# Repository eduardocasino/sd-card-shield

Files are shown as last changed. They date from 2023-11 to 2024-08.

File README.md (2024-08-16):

# SD Card Shield for 8-bit computers

## About

This is a functionally equivalent recreation of the latest version of Corsham's [SD Card Shield](https://www.corshamtech.com/new-version-of-sd-card-shield/). Sadly, Bob Applegate, the man and soul behind Corsham Technologies, passed away in 2023 and [his shop is no longer in business](https://www.corshamtech.com/bad-news-and-the-future/).

Bob put a lot of his work under open source licenses or in the public domain, and also shared the schematics of his boards in the spirit of the emerging personal computer industry of the late 1970s. However, this information was not always complete or up to date, and never published the files to physically reproduce his PCBs (logically, as this was also a business to him) and now those boards are not available anymore.

I have been able to reverse engineer the design from the schematic of previous versions, which is available, and from photos of revisions 6 and 9.

~~WARNING: This design has not been tested yet. Use at your own risk!~~

The board has been tested working with a KIM-1 and Corsham's xKIM monitor but, still, use at your own risk!

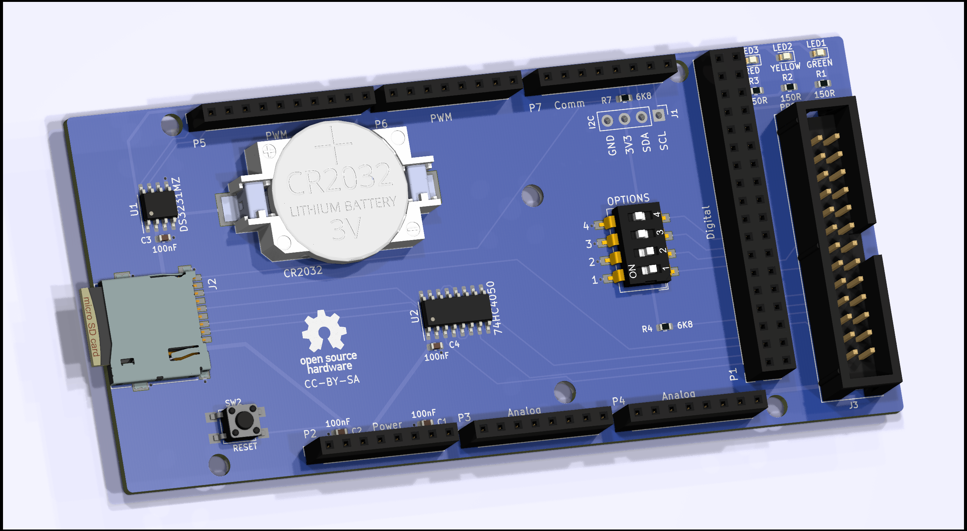
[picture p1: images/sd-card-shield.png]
components

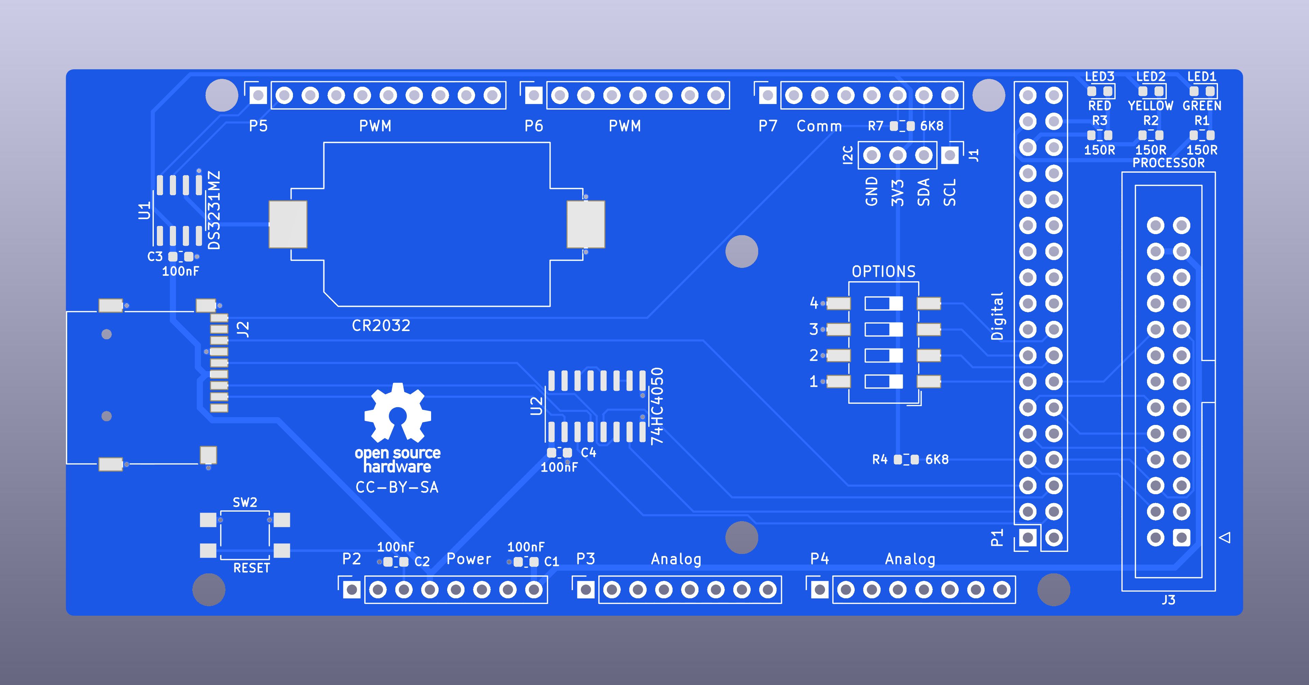
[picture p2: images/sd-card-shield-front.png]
front

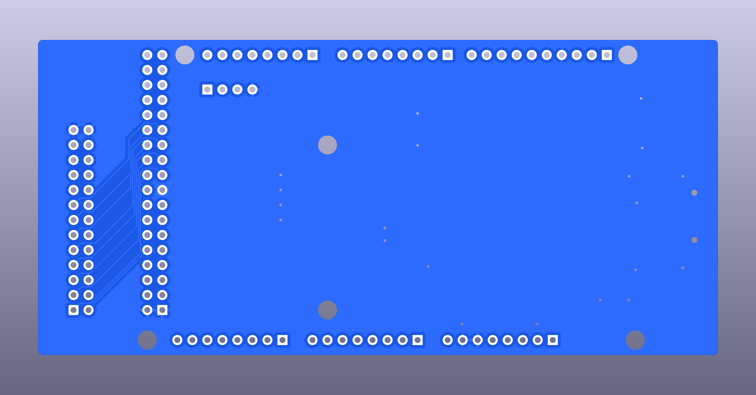
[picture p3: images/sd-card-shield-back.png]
back


## Licensing

This is a personal project that I am sharing in case it is of interest to any retrocomputing enthusiast and all the information in this repository is provided "as is", without warranty of any kind. I am not liable for any damages that may occur, whether it be to individuals, objects, KIM-1 computers, kittens or any other pets. **It should also be noted that everything in this repository is a work in progress, has not been tested and may contain errors, therefore anyone who chooses to use it does so at their own risk**.



This work is licensed under a [Creative Commons Attribution-ShareAlike 4.0 International License](http://creativecommons.org/licenses/by-sa/4.0/).

See the LICENSE.md file for details.

## Acknowledgements

* Bob Applegate, for the original design. 
* Hans Otten and his [Retro Computing blog](http://retro.hansotten.nl/). Pictures and running some checks on his rev6 board.

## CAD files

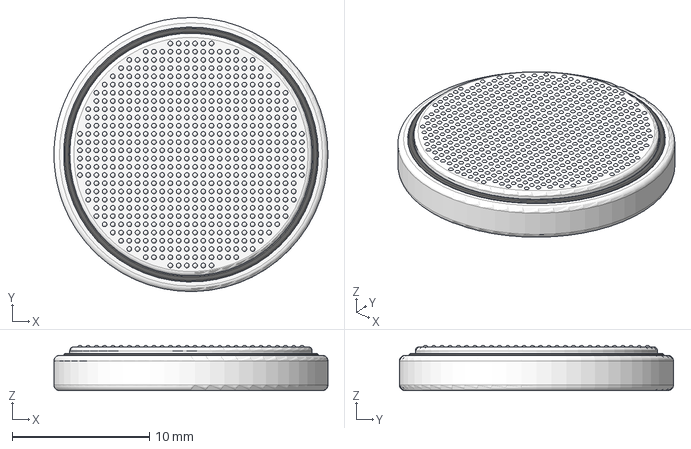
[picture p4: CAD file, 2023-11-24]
3dmodels/CR2032.stp
20.0 x 20.0 x 3.30 mm

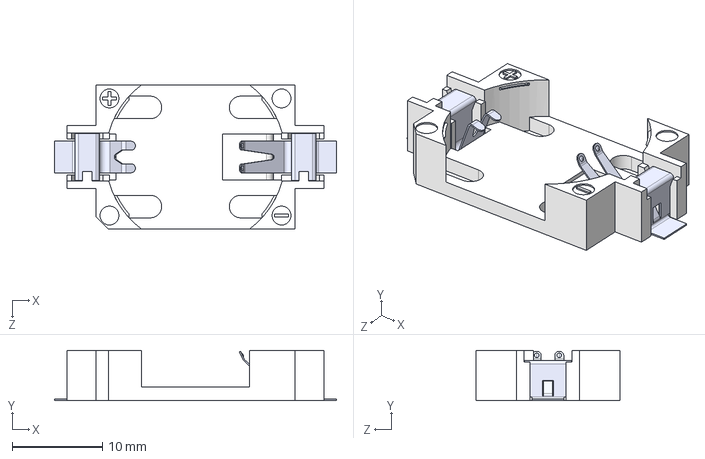
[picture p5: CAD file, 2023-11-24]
3dmodels/CR2032-BS-6-1.step
31.3 x 5.55 x 16.0 mm

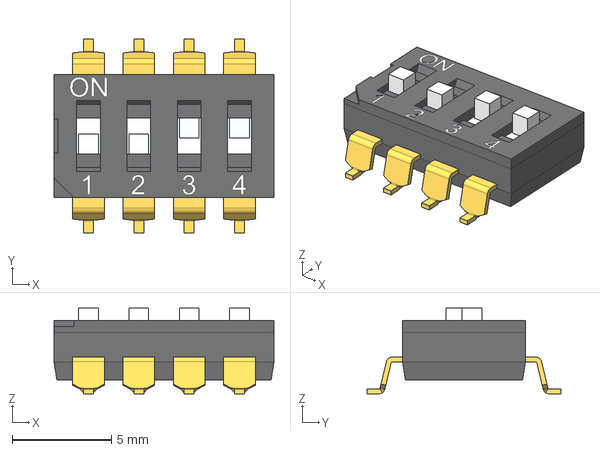
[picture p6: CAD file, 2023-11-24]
3dmodels/DIP Switch 4 positions SMD.stp
11.1 x 9.80 x 4.32 mm

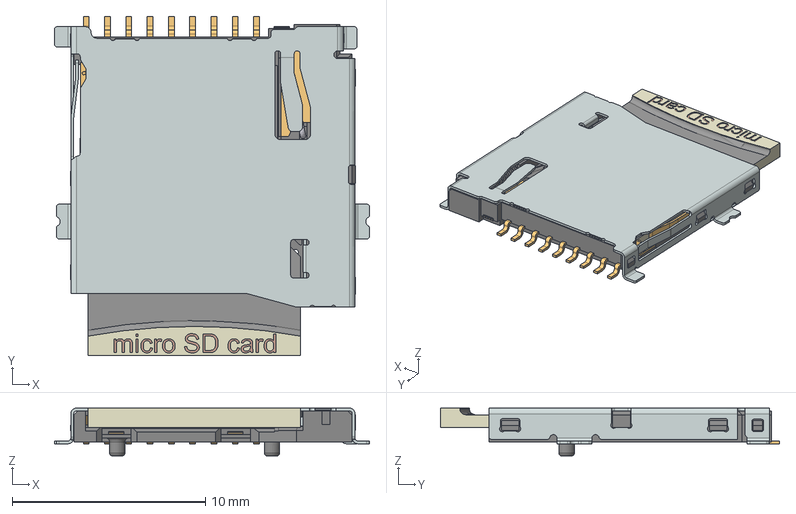
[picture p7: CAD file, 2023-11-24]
3dmodels/Micro_SD_Card_and_Holder.stp
16.3 x 17.5 x 2.48 mm
693071020811_Housing
693071020811_Guide
693071020811_Spring
693071020811_Contact
693071020811_Hook
693071020811_Agraphe
693071020811_Shielding
MicroSD

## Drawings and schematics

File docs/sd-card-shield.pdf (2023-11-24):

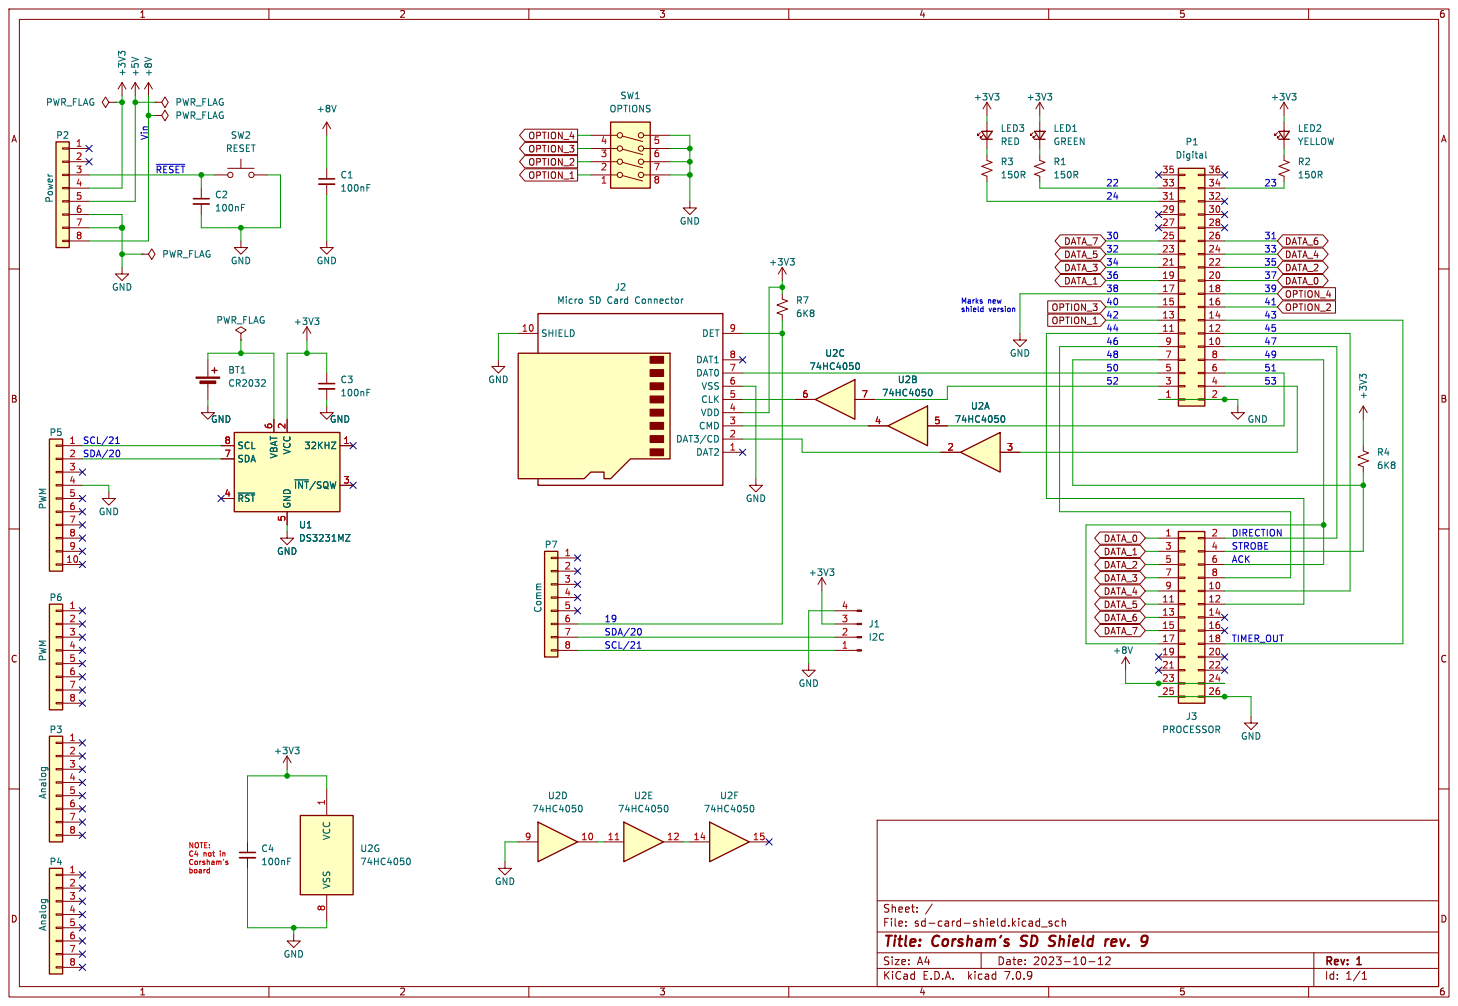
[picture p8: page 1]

6 SDA 7 SCL 8 U1 DS3231MZ GND GND +3V3 +5V

J2 Micro SD Card Connector C4

Id: 1/1 Title: Corsham's SD Shield rev. 9

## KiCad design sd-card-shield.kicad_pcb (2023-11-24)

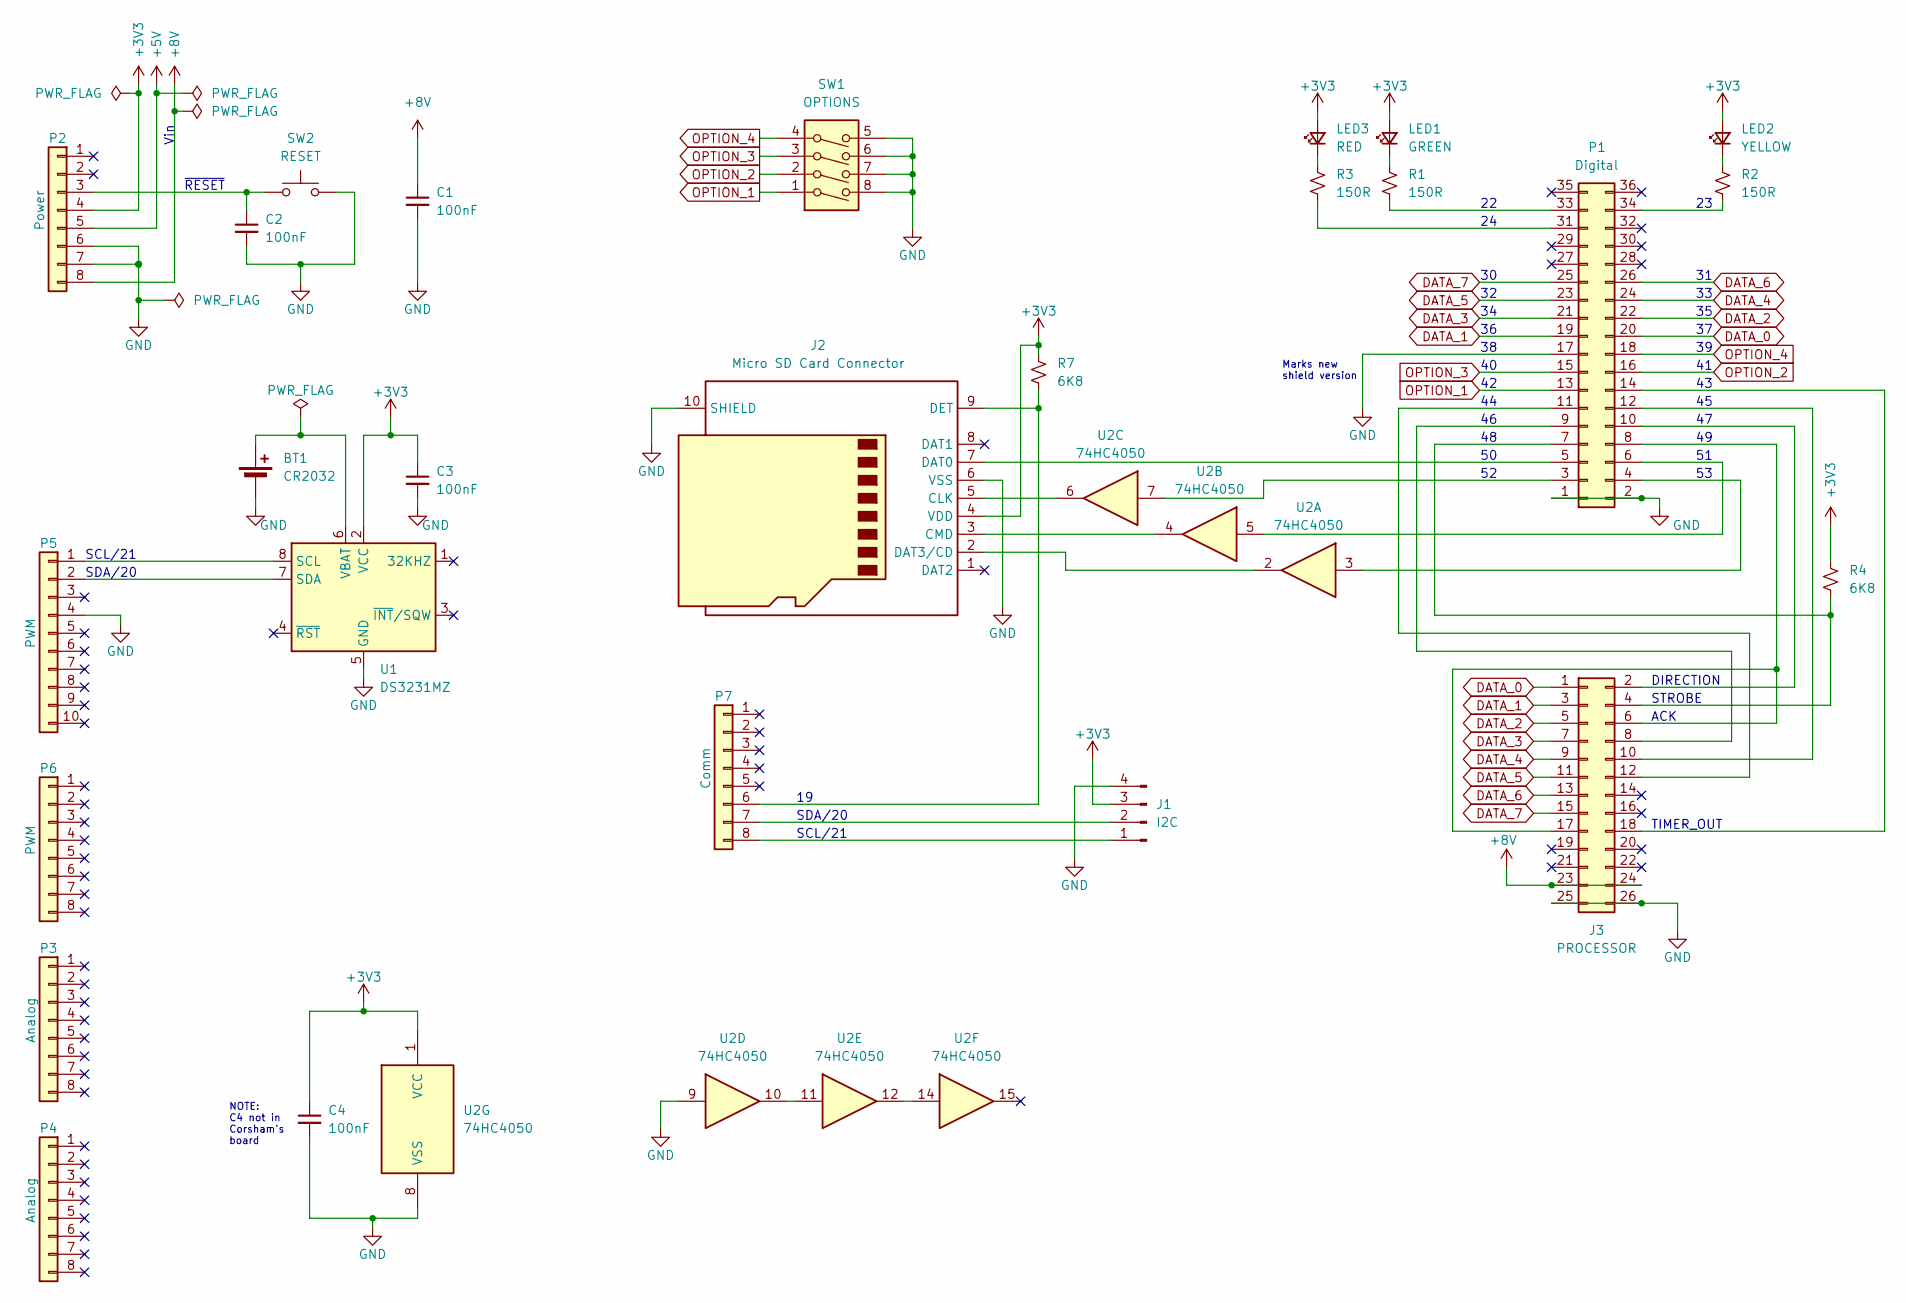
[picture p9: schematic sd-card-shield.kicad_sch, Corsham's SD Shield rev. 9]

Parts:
BT1: CR2032; BAT_CR2032-BS-06-B; LCSC C964760
C1, C2, C3, C4: 100nF; C_0603_1608Metric; LCSC C2762593
J1: I2C; PinHeader_1x04_P2.54mm_Vertical
J2: Micro SD Card Connector; SD_Card_Holder_SMD_WQ21801-B2180-7F
J3: PROCESSOR; IDC-Header_2x13_P2.54mm_Vertical; LCSC C7501247
LED1: GREEN; LED_0603_1608Metric; PART SML-D12P8WT86; LCSC C510026
LED2: YELLOW; LED_0603_1608Metric; PART SML-D12Y8WT86; LCSC C2840179
LED3: RED; LED_0603_1608Metric; PART SML-D12V8WT86; LCSC C2693607
P1: Digital; PinSocket_2x18_P2.54mm_Vertical
P2: Power; PinSocket_1x08_P2.54mm_Vertical
P3, P4: Analog; PinSocket_1x08_P2.54mm_Vertical
P5: PWM; PinSocket_1x10_P2.54mm_Vertical
P6: PWM; PinSocket_1x08_P2.54mm_Vertical
P7: Comm; PinSocket_1x08_P2.54mm_Vertical
R1, R2, R3: 150R; R_0603_1608Metric; LCSC C270843
R4, R7: 6K8; R_0603_1608Metric; LCSC C2074375
SW1: OPTIONS; SW_DIP_SPSTx04_Slide_6x10.22_P2.54mm_DSIC04LSGET; LCSC C54950
SW2: RESET; SW_SPST_TL3305A; LCSC C2886899
U1: DS3231MZ; SOIC-8_3.9x4.9mm_P1.27mm; LCSC C107410
U2: 74HC4050; SOP-16_3.9x9.9mm_P1.27mm; LCSC C43181

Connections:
+3V3: C3.1, C4.1, J1.3, J2.4 (VDD), LED1.2 (A), LED2.2 (A), LED3.2 (A), P2.4, R4.1, R7.1, U1.2 (VCC), U2.1 (VCC)
+5V: P2.5
+8V: C1.1, J3.23, J3.24, P2.8
DATA_0: J3.1, P1.20
DATA_1: J3.3, P1.19
DATA_2: J3.5, P1.22
DATA_3: J3.7, P1.21
DATA_4: J3.9, P1.24
DATA_5: J3.11, P1.23
DATA_6: J3.13, P1.26
DATA_7: J3.15, P1.25
GND: BT1.2 (-), C1.2, C2.2, C3.2, C4.2, J1.4, J2.6 (VSS), J2.10 (SHIELD), J3.25, J3.26, P1.1, P1.2, P1.17, P2.6, P2.7, P5.4, SW1.5, SW1.6, SW1.7, SW1.8, SW2.1, U1.5 (GND), U2.8 (VSS), U2.9
unnamed: BT1.1 (+), U1.6 (VBAT)
unnamed: J1.1, P7.8
unnamed: J1.2, P7.7
unnamed: J2.5 (CLK), U2.6
unnamed: J2.3 (CMD), U2.4
unnamed: J2.7 (DAT0), P1.5
unnamed: J2.2 (DAT3/CD), U2.2
unnamed: J2.9 (DET), P7.6, R7.2
unnamed: J3.2, P1.10
unnamed: J3.4, P1.7, R4.2
unnamed: J3.8, P1.9
unnamed: J3.10, P1.12
unnamed: J3.12, P1.11
unnamed: J3.6, J3.17, P1.8
unnamed: J3.18, P1.14
unnamed: LED1.1 (K), R1.1
unnamed: LED2.1 (K), R2.1
unnamed: LED3.1 (K), R3.1
unnamed: P1.3, U2.7
unnamed: P1.4, U2.3
unnamed: P1.6, U2.5
unnamed: P1.31, R3.2
unnamed: P1.33, R1.2
unnamed: P1.34, R2.2
unnamed: C2.1, P2.3, SW2.2
unnamed: P5.1, U1.8 (SCL)
unnamed: P5.2, U1.7 (SDA)
unnamed: U2.10, U2.11
unnamed: U2.12, U2.14
OPTION_1: P1.13, SW1.1
OPTION_2: P1.16, SW1.2
OPTION_3: P1.15, SW1.3
OPTION_4: P1.18, SW1.4

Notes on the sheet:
TIMER_OUT
Vin
~{RESET}
NOTE: C4 not in Corsham's board
SDA/20
STROBE
DIRECTION
SCL/21
Marks new shield version
ACK

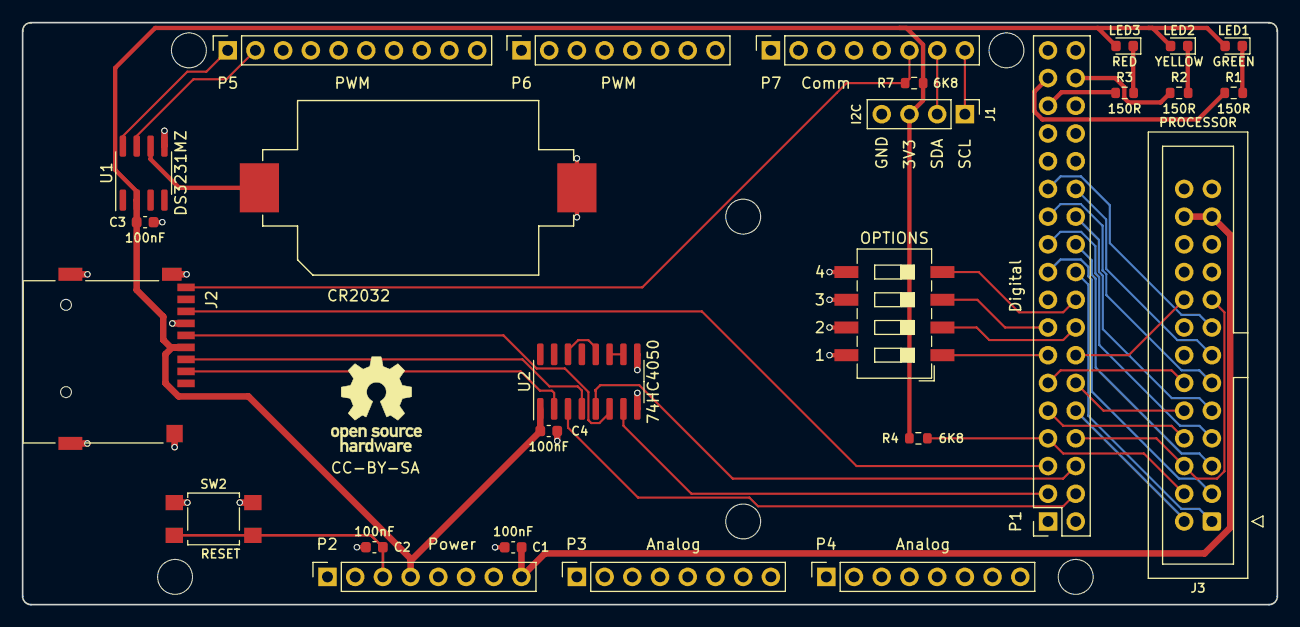
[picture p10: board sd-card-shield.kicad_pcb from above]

Board: 2 copper layers, 115.0 x 53.3 mm, 33 parts (0 on the bottom side), 44 nets.

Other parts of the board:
MH1, MH2, MH3, MH4, MH5, MH6: MountingHole_3.2mm

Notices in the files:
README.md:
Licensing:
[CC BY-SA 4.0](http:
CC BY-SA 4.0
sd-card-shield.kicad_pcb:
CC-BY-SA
